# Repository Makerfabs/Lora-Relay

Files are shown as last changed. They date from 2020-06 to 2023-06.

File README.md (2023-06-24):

# Lora-Relay

```c++
/*
Version:		V2.0
Author:			UNKOWN
Create Date:	UNKOWN
Note:
	2020/7/23	v2.0: Rebuid readme,add pic. By Vincent
*/
```

[toc]

# Introduce

Lora Relay based on the Arduino, users can program it with Arduino IDE, which is very easy especially suit for the none-programmers. There are also guide for users to learn how to create the first IoT project with this board, with which the starters can learn the hardware and programming skill quickly.

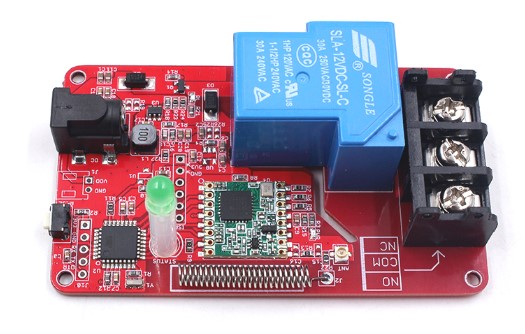
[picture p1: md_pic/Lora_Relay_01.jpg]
relay


- You can get one from: [Lora-Relay](https://www.makerfabs.com/lora-relay-30a.html)

- Hardware and detailed instructions please visit Wiki page:  [Lora-Relay Wiki](https://wiki.makerfabs.com/Lora_Relay.html)

# Related Projects

## [Project_Lora-Relay-Wifi](https://github.com/Makerfabs/Project_Lora-Relay-Wifi)

- Control relay through wifi.

- [YOUTUBE:Lora relay](https://youtu.be/7O8pRCf0avk)

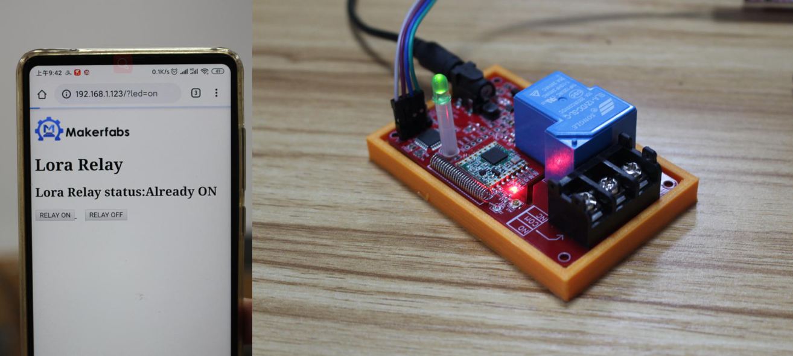
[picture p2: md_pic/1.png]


## [Lora IoT Irrigation System](https://github.com/Makerfabs/Project_IoT-Irrigation-System)

- IoT agricultural irrigation experiment based on Lora communication.
- [YOUTUBE:Lora IoT Irrigation System - Outdoor Simulation Test](https://youtu.be/0mY6Ox0YvRk)

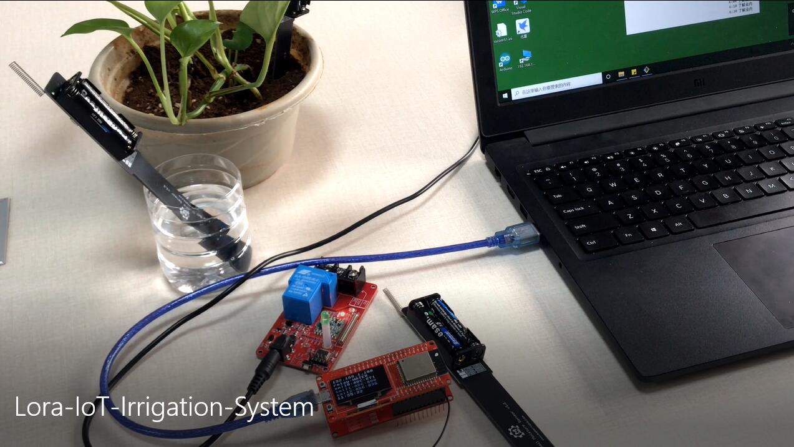
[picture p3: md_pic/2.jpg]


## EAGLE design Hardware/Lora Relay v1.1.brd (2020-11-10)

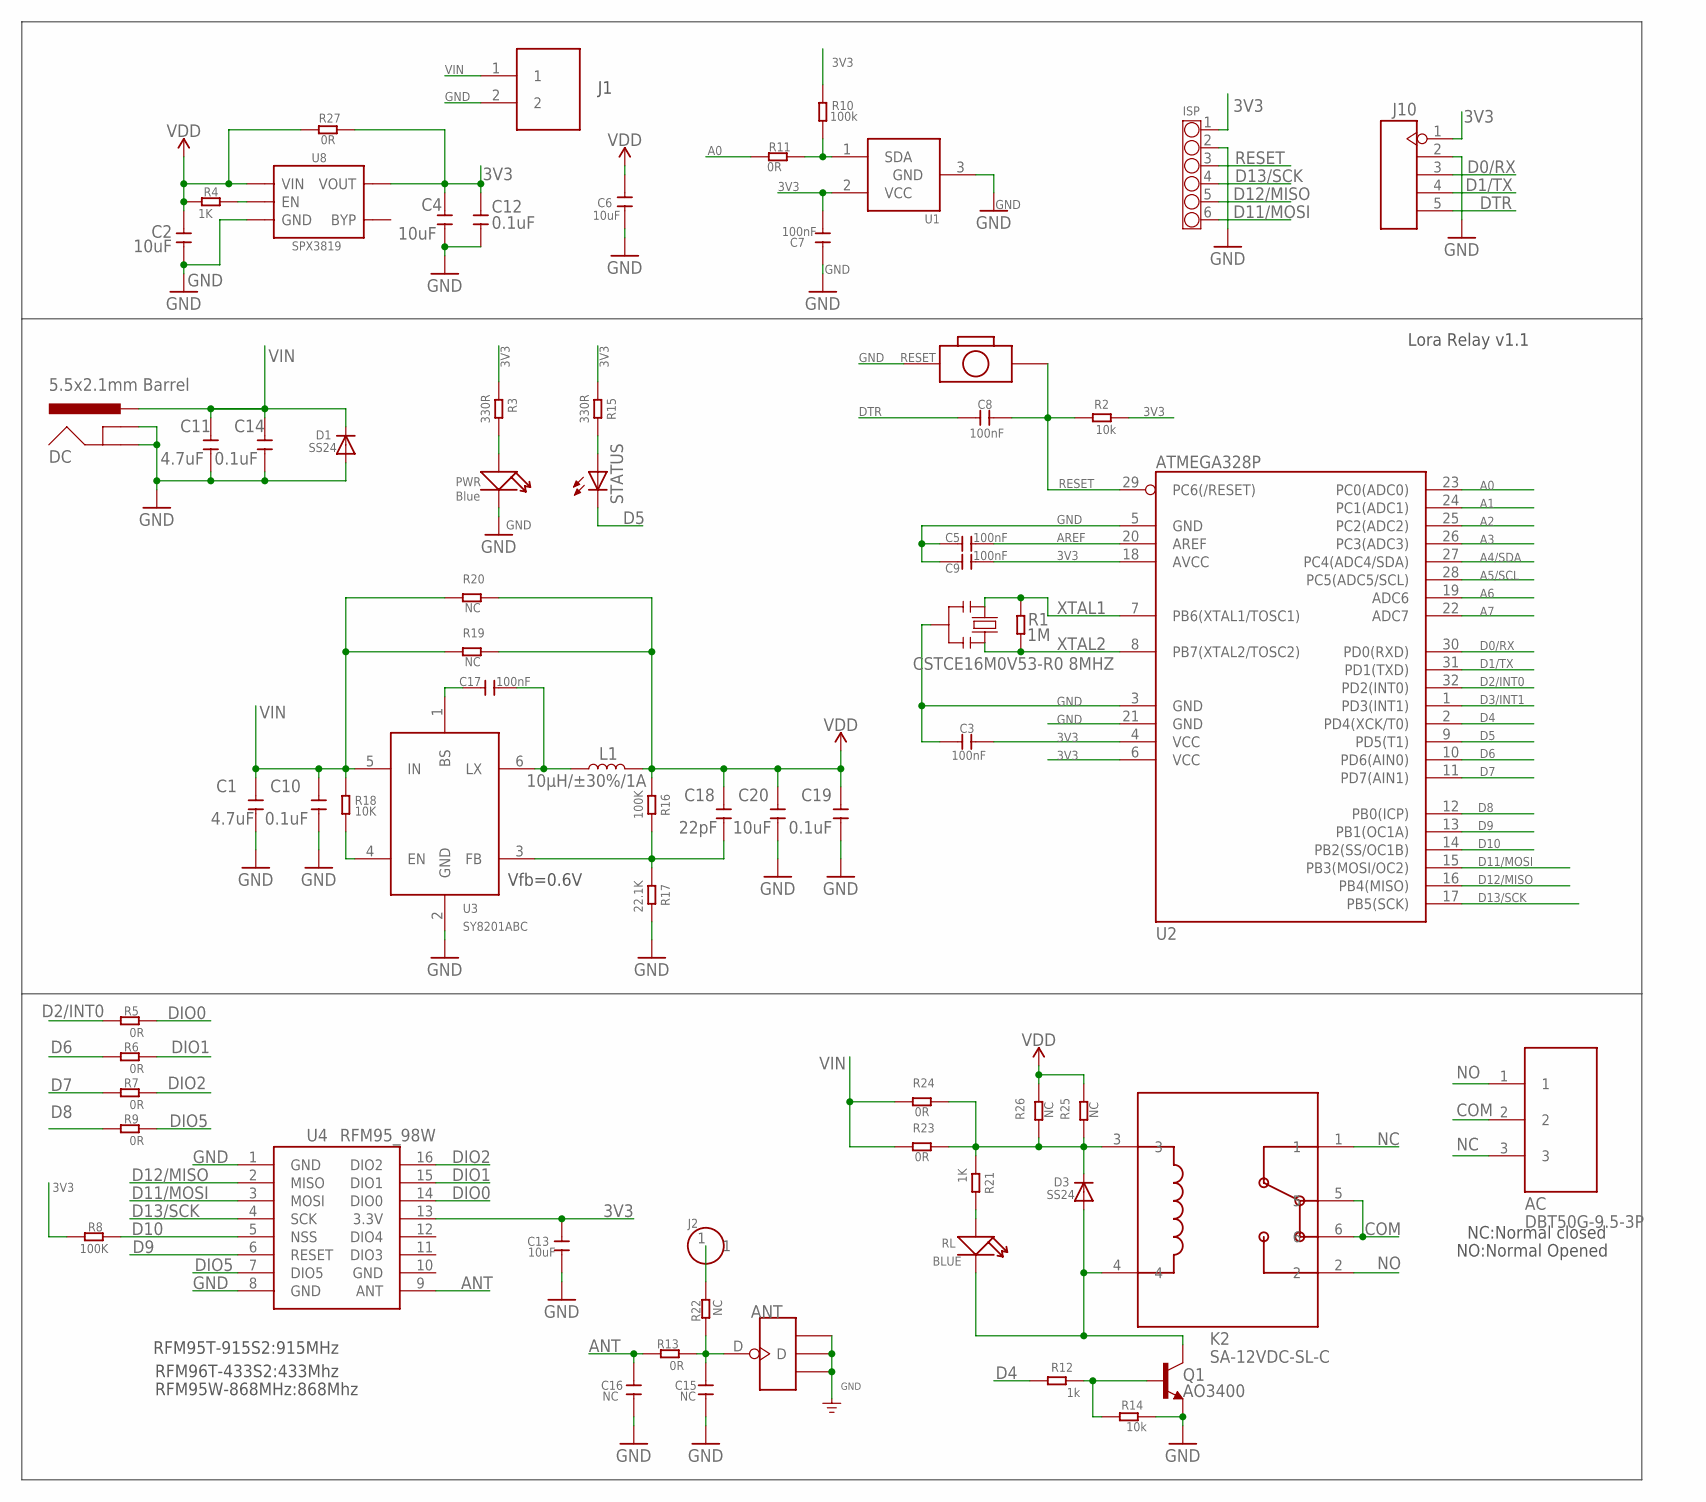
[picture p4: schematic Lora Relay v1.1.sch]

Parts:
AC: DBT50G-9.5-3P; THROUGH-HOLE-9.5
ANT: ANTENNA-U-FL; 4P-U-FL
C1, C11: 4.7uF; 0603
C2, C4, C6, C13, C20: 10uF; 0603
C3, C5, C7, C8, C9, C17: 100nF; 0603
C10, C12, C14, C19: 0.1uF; 0603
C15, C16: NC; 0603
C18: 22pF; 0603
D1, D3: SS24; SMADIODE
DC: 5.5x2.1mm Barrel; POWER_JACK_SMD
ISP: CONNECTOR-HEADER-6P-3460270P1; 1X6P-2.54-8.5-BLACK-FEMALE
J1: PH2.0-2P-90-DIP
J2: HEADER-1P-50; 1P-100/50MIL
J10: HEADER-5P-2.54; 5P-2.54
K2: SA-12VDC-SL-C; THROUGH-HOLE
L1: 10µH/±30%/1A; CR54
PWR: Blue; LED-0603
Q1: AO3400; SOT23-3
R1: 1M; R0603
R2, R14: 10k; R0603
R3, R15: 330R; R0603
R4, R21: 1K; R0603
R5, R6, R7, R9, R11, R13, R23, R24, R27: 0R; R0603
R8, R16: 100K; R0603
R10: 100k; R0603
R12: 1k; R0603
R17: 22.1K; R0603
R18: 10K; R0603
R19, R20, R22, R25, R26: NC; R0603
RESET: BOTTON-2P-90D; 2P-7.62X3.56-90D
RL: BLUE; LED-0603
STATUS: LED5MM
U1: IC_ATSHA204A_CRYPT; SOT23-3
U2: ATMEGA328P; TQFP32
U3: SY8201ABC; SOT-23-6
U4: RFM95_98W; RFM92_93W
U8: SPX3819; SOT23-5
Y1: CSTCE16M0V53-R0 8MHZ; RESONATOR

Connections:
3V3: C3.2, C4.2, C7.2, C9.2, C12.2, C13.2, ISP.1, J10.1, R2.1, R3.1, R8.2, R10.1, R15.1, R27.2, U1.2 (VCC), U2.4 (VCC), U2.6 (VCC), U2.18 (AVCC), U4.13 (3.3V), U8.5 (VOUT)
A0: R11.1, U2.23 (PC0(ADC0))
A1: U2.24 (PC1(ADC1))
A2: U2.25 (PC2(ADC2))
A3: U2.26 (PC3(ADC3))
A4/SDA: U2.27 (PC4(ADC4/SDA))
A5/SCL: U2.28 (PC5(ADC5/SCL))
A6: U2.19 (ADC6)
A7: U2.22 (ADC7)
ANT: C16.2, R13.2, U4.9 (ANT)
AREF: C5.2, U2.20 (AREF)
COM: AC.2, K2.5, K2.6
D0/RX: J10.3, U2.30 (PD0(RXD))
D1/TX: J10.4, U2.31 (PD1(TXD))
D2/INT0: R5.1, U2.32 (PD2(INT0))
D3/INT1: U2.1 (PD3(INT1))
D4: R12.2, U2.2 (PD4(XCK/T0))
D5: STATUS.K (C), U2.9 (PD5(T1))
D6: R6.1, U2.10 (PD6(AIN0))
D7: R7.1, U2.11 (PD7(AIN1))
D8: R9.1, U2.12 (PB0(ICP))
D9: U2.13 (PB1(OC1A)), U4.6 (RESET)
D10: R8.1, U2.14 (PB2(SS/OC1B)), U4.5 (NSS)
D11/MOSI: ISP.6, U2.15 (PB3(MOSI/OC2)), U4.3 (MOSI)
D12/MISO: ISP.5, U2.16 (PB4(MISO)), U4.2 (MISO)
D13/SCK: ISP.4, U2.17 (PB5(SCK)), U4.4 (SCK)
DIO0: R5.2, U4.14 (DIO0)
DIO1: R6.2, U4.15 (DIO1)
DIO2: R7.2, U4.16 (DIO2)
DIO5: R9.2, U4.7 (DIO5)
DTR: C8.1, J10.5
GND: ANT.GND1, ANT.GND2, ANT.GND3, C1.1, C2.1, C3.1, C4.1, C5.1, C6.1, C7.1, C9.1, C10.1, C11.1, C12.1, C13.1, C14.1, C15.1, C16.1, C19.1, C20.1, D1.A, DC.GND (GNDBREAK), DC.P$4 (GND), ISP.2, J1.2, J10.2, PWR.-, Q1.2 (E), R14.2, R17.2, RESET.P$1 (1), U1.3 (GND), U2.3 (GND), U2.5 (GND), U2.21 (GND), U3.2 (GND), U4.1 (GND), U4.8 (GND), U4.10 (GND), U8.2 (GND), Y1.2
unnamed: D3.A, K2.4, Q1.3 (C), RL.-
unnamed: R10.2, R11.2, U1.1 (SDA)
unnamed: Q1.1 (B), R12.1, R14.1
unnamed: ANT.D, C15.2, R13.1, R22.2
unnamed: R15.2, STATUS.A
unnamed: C17.2, L1.P$1 (1), U3.6 (LX)
unnamed: PWR.+, R3.2
unnamed: C17.1, U3.1 (BS)
unnamed: R21.2, RL.+
unnamed: C18.1, R16.2, R17.1, U3.3 (FB)
unnamed: R18.2, U3.4 (EN)
unnamed: J2.1, R22.1
unnamed: D3.C, K2.3, R21.1, R23.2, R24.2, R25.1, R26.1
unnamed: R4.2, U8.3 (EN)
NC: AC.3, K2.1
NO: AC.1, K2.2
RESET: C8.2, ISP.3, R2.2, RESET.P$2 (2), U2.29 (PC6(/RESET))
VDD: C2.2, C6.2, C18.2, C19.2, C20.2, L1.P$2 (2), R4.1, R16.1, R19.2, R20.2, R25.2, R26.2, R27.1, U8.1 (VIN)
VIN: C1.2, C10.2, C11.2, C14.2, D1.C, DC.VIN0 (PWR), J1.1, R18.1, R19.1, R20.1, R23.1, R24.1, U3.5 (IN)
XTAL1: R1.2, U2.7 (PB6(XTAL1/TOSC1)), Y1.1
XTAL2: R1.1, U2.8 (PB7(XTAL2/TOSC2)), Y1.3

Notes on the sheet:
RFM95T-915S2:915MHz
RFM96T-433S2:433Mhz
RFM95W-868MHz:868Mhz
NC:Normal closed
NO:Normal Opened
Lora Relay v1.1
Vfb=0.6V

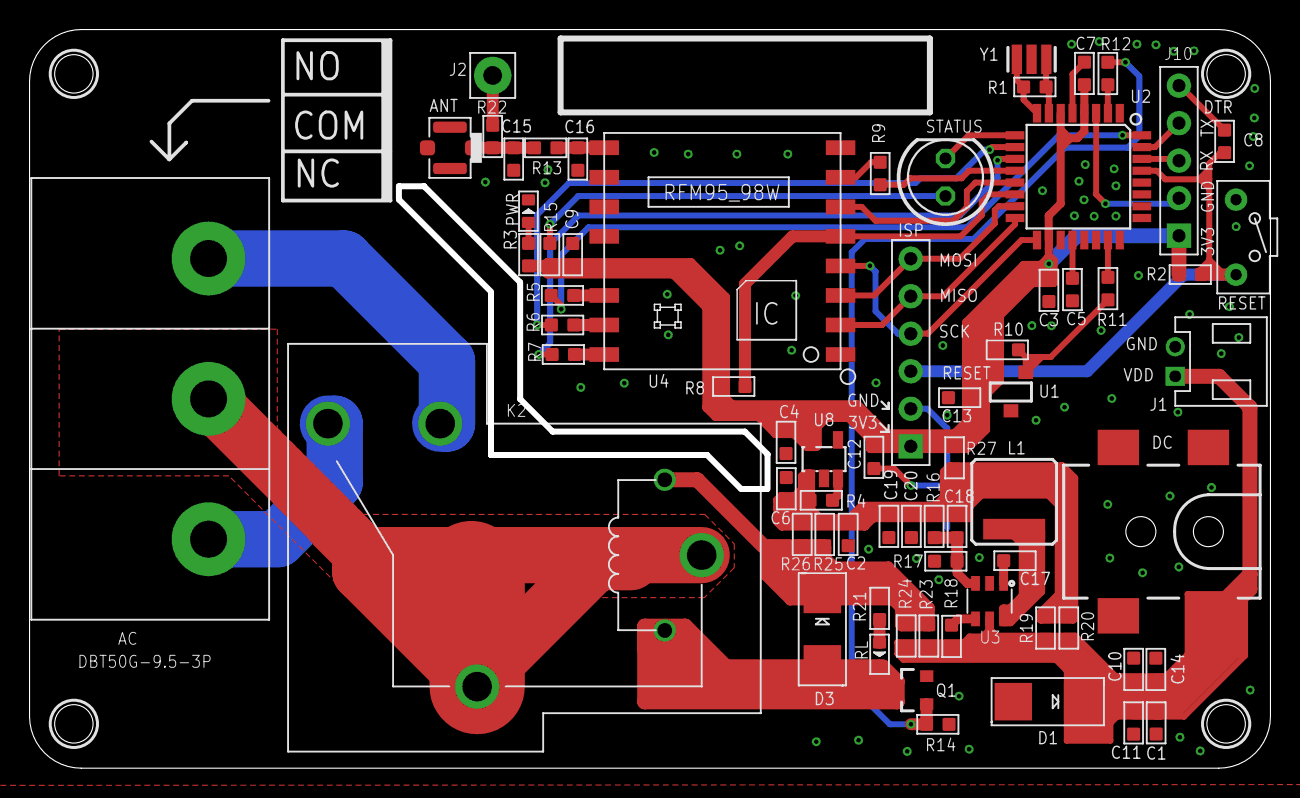
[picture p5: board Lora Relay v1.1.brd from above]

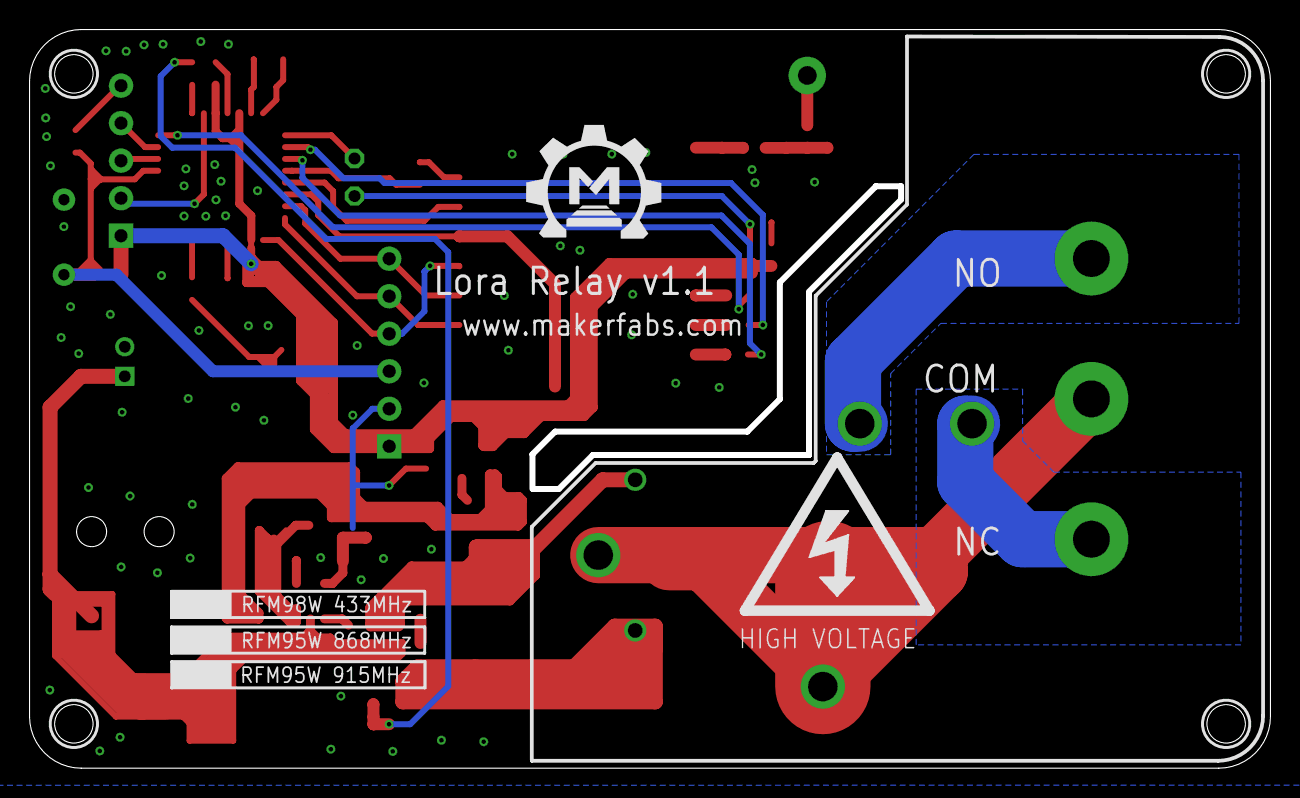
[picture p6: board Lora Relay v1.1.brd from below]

Board: 2 copper layers, 84.0 x 50.0 mm, 71 parts (2 on the bottom side), 45 nets.

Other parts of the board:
U$1: MAKERFABS_0.3
U$3: HIGH-VOLTAGE-1.5

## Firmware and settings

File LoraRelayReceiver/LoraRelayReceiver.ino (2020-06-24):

// Arduino9x_RX
// -*- mode: C++ -*-
// Example sketch showing how to create a simple messaging client (receiver)
// with the RH_RF95 class. RH_RF95 class does not provide for addressing or
// reliability, so you should only use RH_RF95 if you do not need the higher
// level messaging abilities.
// It is designed to work with the other example Arduino9x_TX
 
#include <SPI.h>
#include <RH_RF95.h>
 
#define RFM95_CS 10
#define RFM95_RST 9
#define RFM95_INT 2
 
// Change to 434.0 or other frequency, must match RX's freq!
#define RF95_FREQ 433.0
 
// Singleton instance of the radio driver
RH_RF95 rf95(RFM95_CS, RFM95_INT);
 
// Blinky on receipt
#define LED 5

#define RELAY_IO   4

int count=0;

void TurnOnRelay(void)
{
  digitalWrite(RELAY_IO, HIGH);
  delay(100);
}

void TurnOffRelay(void)
{
  digitalWrite(RELAY_IO, LOW);
  delay(100);
}

void setup() 
{
  pinMode(LED, OUTPUT);
  pinMode(RELAY_IO, OUTPUT);
   
  pinMode(RFM95_RST, OUTPUT);
  digitalWrite(RFM95_RST, HIGH);
 
  //while (!Serial);
  Serial.begin(115200);
  delay(100);
 
  Serial.println("Arduino LoRa RX Test!");
  
  // manual reset
  digitalWrite(RFM95_RST, LOW);
  delay(10);
  digitalWrite(RFM95_RST, HIGH);
  delay(10);
 
  while (!rf95.init()) {
    Serial.println("LoRa radio init failed");
    while (1);
  }
  Serial.println("LoRa radio init OK!");
 
  // Defaults after init are 434.0MHz, modulation GFSK_Rb250Fd250, +13dbM
  if (!rf95.setFrequency(RF95_FREQ)) {
    Serial.println("setFrequency failed");
    while (1);
  }
  Serial.print("Set Freq to: "); Serial.println(RF95_FREQ);
 
  // Defaults after init are 434.0MHz, 13dBm, Bw = 125 kHz, Cr = 4/5, Sf = 128chips/symbol, CRC on
 
  // The default transmitter power is 13dBm, using PA_BOOST.
  // If you are using RFM95/96/97/98 modules which uses the PA_BOOST transmitter pin, then 
  // you can set transmitter powers from 5 to 23 dBm:
  rf95.setTxPower(23, false);
}
 
void loop()
{
  if (rf95.available())
  {
    
    // Should be a message for us now   
    uint8_t buf[RH_RF95_MAX_MESSAGE_LEN];
    uint8_t len = sizeof(buf);
    
    if (rf95.recv(buf, &len))
    {
      count++;
      digitalWrite(LED, HIGH);
      RH_RF95::printBuffer("Received: ", buf, len);
      Serial.print("Got: ");
      Serial.println((char*)buf);
      Serial.print("RSSI: ");
      Serial.println(rf95.lastRssi(), DEC);

      if(count%2==1)
        TurnOnRelay();
      else
        TurnOffRelay();
       
      // Send a reply
      uint8_t data[] = "And hello back to you";
      rf95.send(data, sizeof(data));
      rf95.waitPacketSent();
      Serial.println("Sent a reply");
      digitalWrite(LED, LOW);
    }
    else
    {
      Serial.println("Receive failed");
    }
  }
}

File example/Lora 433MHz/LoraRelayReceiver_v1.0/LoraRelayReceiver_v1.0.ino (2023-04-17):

/*

Author:         Vincent
Create date:    2022/3/24
Version:        1.0

Command example:

  ACT = 0 Close
    ID020001ACT000PARAM000000#

  ACT = 1 All Open
    ID020001ACT001PARAM000000#

  ACT = 2 Relay Control 
    PARAM = 0000-1111 Relay Status
    ID020001ACT002PARAM001010

*/

// include the library
#include <RadioLib.h>

#define DIO0 2
#define DIO1 6
#define DIO2 7
#define DIO5 8

#define LORA_RST 9
#define LORA_CS 10

#define SPI_MOSI 11
#define SPI_MISO 12
#define SPI_SCK 13

// Blinky on receipt
#define LED 5

String node_id = String("ID") + "020002";
int id_number_length = 6;
String debug_id = "IDXDEBUG";

/*
Begin method:
Carrier frequency: 434.0 MHz (for SX1276/77/78/79 and RFM96/98) or 915.0 MHz (for SX1272/73 and RFM95/97)
Bandwidth: 125.0 kHz (dual-sideband)
Spreading factor: 9
Coding rate: 4/7
Sync word: SX127X_SYNC_WORD (0x12)
Output power: 10 dBm
Preamble length: 8 symbols
Gain: 0 (automatic gain control enabled)
Other:
Over-current protection: 60 mA
Inaccessible:
LoRa header mode: explicit
Frequency hopping: disabled

*/

#define FREQUENCY 434.0
#define BANDWIDTH 125.0
#define SPREADING_FACTOR 9
#define CODING_RATE 7
#define OUTPUT_POWER 10
#define PREAMBLE_LEN 8
#define GAIN 0

SX1276 radio = new Module(LORA_CS, DIO0, LORA_RST, DIO1);
//SX1278 radio = new Module(LORA_CS, DIO0, LORA_RST, DIO1, SPI, SPISettings());
int relay_status[4] = {0, 0, 0, 0};
int relay_pin[4] = {4, -1, -1, -1};

void setup()
{
    Serial.begin(115200);
		pinMode(LED, OUTPUT);
		digitalWrite(LED, LOW);
    pin_init();
    relay_control(0);

    // initialize SX1278 with default settings
    Serial.print(F("[SX1278] Initializing ... "));

    int state = radio.begin(FREQUENCY, BANDWIDTH, SPREADING_FACTOR, CODING_RATE, SX127X_SYNC_WORD, OUTPUT_POWER, PREAMBLE_LEN, GAIN);

    if (state == ERR_NONE)
    {
        Serial.println(F("success!"));
    }
    else
    {
        Serial.print(F("failed, code "));
        Serial.println(state);
        while (true)
            ;
    }
}

void loop()
{
    //Serial.print(F("[SX1278] Waiting for incoming transmission ... "));

    String str;
    int state = radio.receive(str);

    if (state == ERR_NONE)
    {
    		digitalWrite(LED, HIGH);
        // packet was successfully received
        Serial.println(F("success!"));

        // print the data of the packet
        Serial.print(F("[SX1278] Data:\t\t\t"));
        Serial.println(str);

        // print the RSSI (Received Signal Strength Indicator)
        // of the last received packet
        Serial.print(F("[SX1278] RSSI:\t\t\t"));
        Serial.print(radio.getRSSI());
        Serial.println(F(" dBm"));

        // print the SNR (Signal-to-Noise Ratio)
        // of the last received packet
        Serial.print(F("[SX1278] SNR:\t\t\t"));
        Serial.print(radio.getSNR());
        Serial.println(F(" dB"));

        // print frequency error
        // of the last received packet
        Serial.print(F("[SX1278] Frequency error:\t"));
        Serial.print(radio.getFrequencyError());
        Serial.println(F(" Hz"));

        if (command_explain(str))
        {
            //String back_str = node_id + " REPLY : RELAY4 " + String("STATUS DATA");
            char reply_cstr[20];
            sprintf(reply_cstr, "%04d", get_relay_status());
            String back_str = node_id + " REPLY : RELAY " + reply_cstr;
            radio.transmit(back_str);
        }
        digitalWrite(LED, LOW);
    }
    else if (state == ERR_RX_TIMEOUT)
    {
        // timeout occurred while waiting for a packet
        //Serial.println(F("timeout!"));
    }
    else if (state == ERR_CRC_MISMATCH)
    {
        // packet was received, but is malformed
        Serial.println(F("CRC error!"));
    }
    else
    {
        // some other error occurred
        Serial.print(F("failed, code "));
        Serial.println(state);
    }
}

void pin_init()
{
    //{4, 3, A3, A2};
    pinMode(4, OUTPUT);
    pinMode(3, OUTPUT);
    pinMode(A3, OUTPUT);
    pinMode(A2, OUTPUT);
}

int command_explain(String str)
{
    //string spilt
    String txt = str;
    if (txt.startsWith(node_id) || txt.startsWith(debug_id))
    {
        //int node_id = (txt.substring(2, 5)).toInt();
        long node_act = txt.substring(id_number_length + 5, id_number_length + 8).toInt();
        int node_param = txt.substring(id_number_length + 14, id_number_length + 20).toInt();

        Serial.println("ACT:  " + String(node_act));
        Serial.println("PARAM: " + String(node_param));

        switch (node_act)
        {
        case 0:
            Serial.println("ALL CLOSE");
            relay_control(0000);
            break;

        case 1:
            Serial.println("ALL OPEN");
            relay_control(1111);
            break;

        case 2:
            Serial.println("Relay Control");
            relay_control(node_param);
            break;

        case 114:
            Serial.println("CHECK STATUS");
            break;

        default:
            Serial.println("UNKNOWN ACT!");
            return 0;
        }
        return 1;
    }

    return 0;
}

void relay_control(int value)
{

    for (int i = 0; i < 4; i++)
    {
        relay_status[i] = value % 10;
        if (relay_pin[i] != -1)
        {
            digitalWrite(relay_pin[i], relay_status[i]);
        }
        value /= 10;
    }
}

int get_relay_status()
{
    int status = 0;
    for (int i = 3; i >= 0; i--)
    {
        status *= 10;
        status += relay_status[i];
    }

    return status;
}

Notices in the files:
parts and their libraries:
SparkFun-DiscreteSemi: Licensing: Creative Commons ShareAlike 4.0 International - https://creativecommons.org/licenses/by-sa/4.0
